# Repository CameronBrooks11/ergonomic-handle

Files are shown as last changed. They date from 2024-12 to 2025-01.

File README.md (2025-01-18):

# Ergonomic Handle

This is an OpenSCAD library to generate an ergonomic handle that distributes hand contact pressure as evenly as possible.

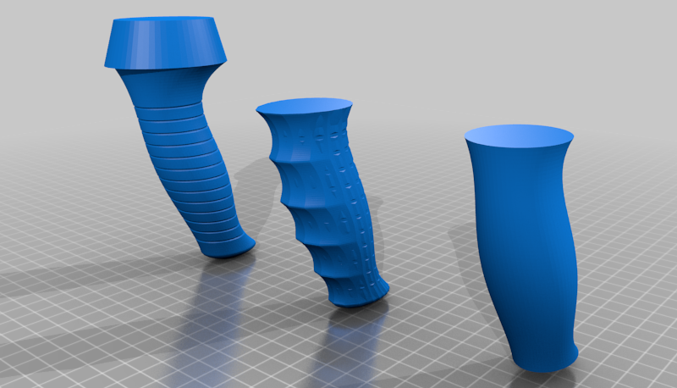
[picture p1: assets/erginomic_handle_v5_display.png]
Ergonomic Handle V5 Render


A further development of "Ergonomic handle based on scientific study": [Thingiverse](https://www.thingiverse.com/thing:5330170) and [Printables](https://www.printables.com/model/154837).

## Summary

The Ergonomic Handle Library is an OpenSCAD library designed to generate ergonomic handles that distribute hand contact pressure as evenly as possible. This library leverages anthropometric data from various populations worldwide to create handles that are both comfortable and scalable to different hand sizes.

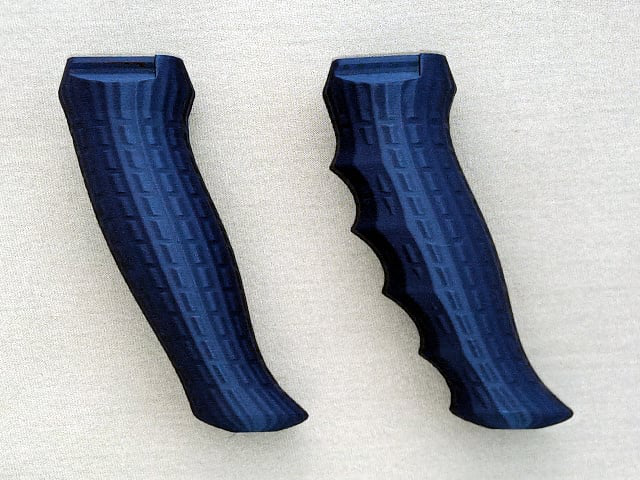
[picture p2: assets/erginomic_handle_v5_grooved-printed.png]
3D Printed Grooved Handle


## Features

- **Scientific Design**: Based on multiple research studies using anthropometric data.
- **Scalable**: Handles can be adjusted to fit any hand size by specifying hand length and width.
- **Customizable**: Various parameters allow for modifications such as finger grooves and handle extensions.
- **Ergonomic**: Designed to distribute pressure evenly across the hand, reducing strain during use.
- **Open Source**: Licensed under Creative Commons - Attribution, allowing for modification and sharing.

## Modules and Parameters

For detailed information on the design see [design details](details.md)!

### `ergonomic_handle`

Renders the body of an ergonomic handle, centered at the origin.

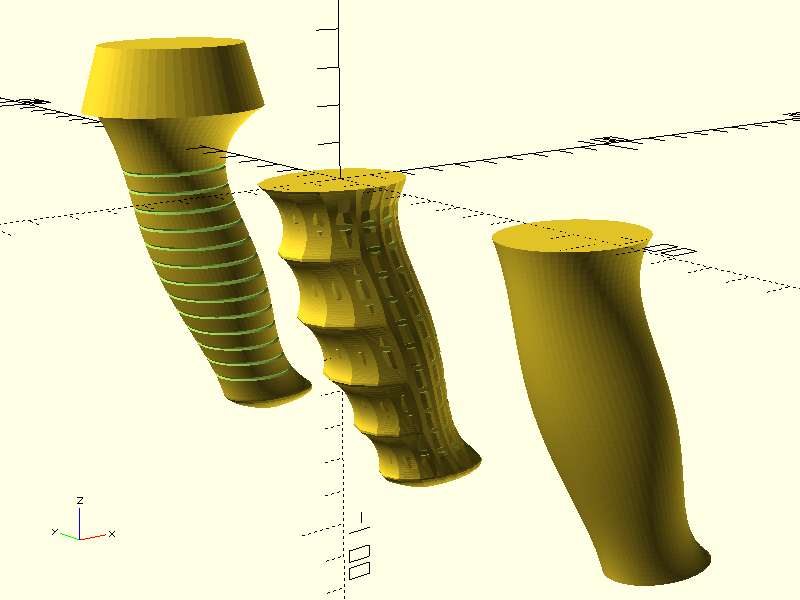
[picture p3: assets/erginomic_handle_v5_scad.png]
OpenSCAD Render


**Parameters:**

- `hand_length` (default: 186): Length of the hand from the tip of the middle finger to the first crease on the wrist, in millimeters.
- `hand_width` (default: 85): Metacarpal breadth; width of the four fingers where they meet the palm, in millimeters.
- `flair` (default: true): Flare out the top and bottom of the front edge for better pull force.
- `bottomcapext` (default: 0): Bottom cap extension. Suggested values: 3 to 8.
- `topext` (default: 0): Top extension, curves extrapolated upward by this amount.
- `groovespc` (default: 0): Groove spacing for improved grip. Suggested spacing: 6-10 mm.
- `fingergroove` (default: false): Enables finger-specific grooves. **Note:** May reduce ergonomic comfort for other hand sizes.
- `tiltangle` (default: 110): Handle tilt angle in degrees. Should be no less than 90.
- `fn` (default: 64): Number of facets in the elliptical cross-section and vertical slices.
- `halfrotate` (default: false): Rotates polygon vertices half of a segment around the ellipse.
- `metacarpal_expansion` (default: 1.12): Expands metacarpal breadth in gripping position. **Range:** 1.10–1.15.
- `groovedepth` (default: 0.6): Depth of grooves, used for creating textured grip.
- `bottomcapscale` (default: 0.3): Scale factor for the bottom-most disc of the handle's base cap.

## Print Settings

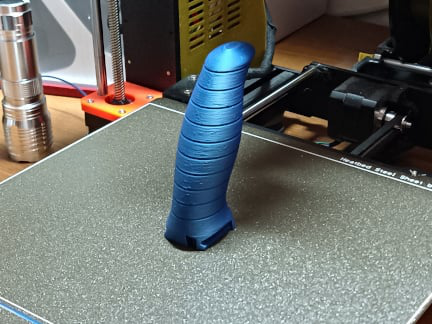
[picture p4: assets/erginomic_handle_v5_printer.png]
Handle on Printer Build Plate


When 3D printing the ergonomic handle, consider the following settings:

- **Printer Brand**: Compatible with Prusa I3 MK3S.
- **Supports**: Not required if printed upside-down. Supports may be needed if printed right-side-up.
- **Infill**: 15% gyroid for optimal strength and material usage.
- **Orientation**: Print the handle upside-down to avoid the need for supports and ensure structural integrity.

**Notes:**

- The handle should be printed upside-down to minimize the need for supports.
- Incorporate a top structure with sliding rails for additional parts to snap into place.

## License

This library is licensed under the Creative Commons - Attribution license (CC BY). You are free to share and adapt the material provided you give appropriate credit.

## Attribution

This project is based on the work of **Alex Matulich**, originally posted on [Thingiverse](https://www.thingiverse.com/thing:5330170) and detailed on his [blog](https://www.nablu.com/2022/03/whose-hands-are-biggest-you-may-be.html). All studies and data used in this library are cited and linked in the original blog article "Whose hands are biggest? You may be surprised."

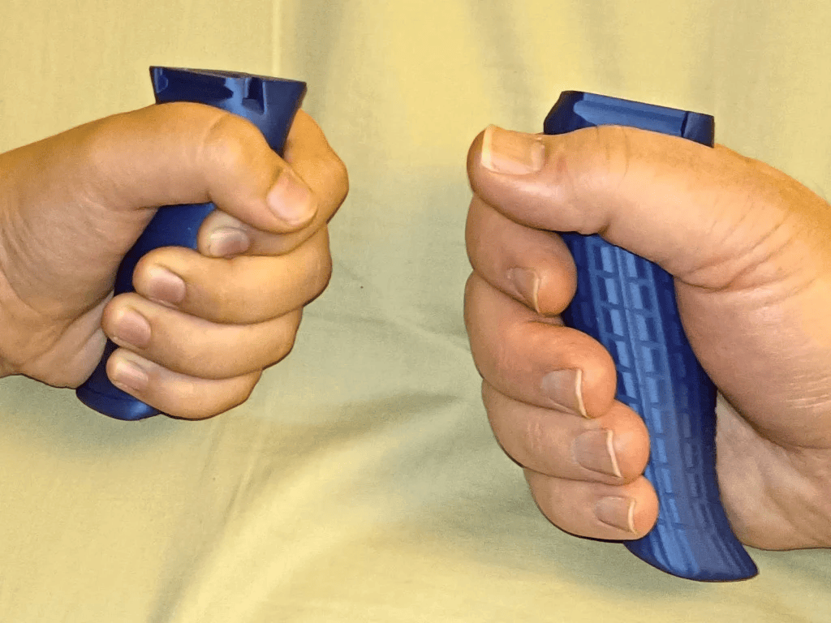
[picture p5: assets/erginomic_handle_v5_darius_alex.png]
Ergonomic Handle Design


For more designs and information, visit Alex's [Thingiverse page](https://www.thingiverse.com/thing:5330170) or his [blog](https://www.nablu.com/2022/03/whose-hands-are-biggest-you-may-be.html).

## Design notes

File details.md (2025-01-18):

# Design Details

An ergonomic handle distributes the hand contact pressure as evenly as possible.

## Basis

The dimensions in this model are based on several research papers using anthropometric data from various populations
around the world. The handle profile is based on a 2020 study in which gripping hands were measured with a contour gauge
to derive the correct curves for an ergonomic handle.

All of these studies are cited and linked in the blog article "[Whose hands are biggest? You may be
surprised.](https://www.nablu.com/2022/03/whose-hands-are-biggest-you-may-be.html)"

The handle contour study was extrapolated by generalizing it to be scalable to any size of hand. Knowing that the handle
height is based on metacarpal breadth (hand width) and the handle cross section sizes are based on hand length, one can
generate vertical and horizontal scale factors for the curve control points given in the study, and thereby obtain a
handle scaled correctly to any size hand.

## Usage

Place this in a searchable location, like the same directory as your script, and near the top, put this line:

use <ergonomic_handle.scad>

## Modules

### Main

`ergonomic_handle(hand_length=185, hand_width=86, flair=true, bottomcapext=0, topext=0, groovespc=0, tiltangle=110, fn=64, halfrotate=false);`

Renders the body of an ergonomic handle. The handle is oriented so that the top surface is centered at the origin.

**Parameters:**

- `hand_length`: Length of hand from tip of middle finger to first crease on wrist. Defaults to `default_hand_length()`.
- `hand_width`: Metacarpal breadth; width of the four fingers where they meet the palm. Defaults to `default_hand_width()`.
- `flair`: Set to `true` to flare out the top and bottom of the front edge for better pull force. When `flair=false`, the handle is generated as described in the referenced study. Defaults to `true`.
- `bottomcapext`: Bottom cap extension. `0` = flat bottom (default). Suggested values range from 3 to 8.
- `topext`: Top extension, curves extrapolated upward by this amount. `0` = no extension (default). The extension extends above the origin.
- `groovespc`: Groove spacing for improved grip. `0` = none (default, or if `fingergroove=true`). Suggested spacing is 6-10 mm. Grooves are 1.2 mm wide and 0.6 mm deep.
- `fingergroove`: Set to `false` for no finger grooves (default), or `true` to include them (this disables `groovespc`). WARNING: Enabling this setting causes the handle to fit ONLY the hand for which it is sized! The grooves are un-ergonomic and uncomfortable if the handle size doesn't match the hand.
- `tiltangle`: Handle tilt angle. `110°` (default) recommended. Should be no less than 90°.
- `fn`: Number of facets (default 64) in elliptical cross-section as well as vertical slices. Vertical slices are always 128 if `fingergroove=true`.
- `halfrotate`: Whether to rotate polygon vertices half of a segment around the ellipse (default `false`). Useful only for overlapping two low-poly handles for interesting textures (see demo).

### Helpers

`ergonomic_handle_top_ellipse(hand_length, hand_width, topext, tiltangle, fn);`

Returns a polygon corresponding to the top surface of the handle (including extension). Parameters are the same as described above. All have defaults if omitted.

`ergonomic_handle_bottom_ellipse(hand_length, hand_width, tiltangle, fn);`

Returns a polygon corresponding to the bottom surface of the handle (excluding bottom cap extension). Useful when not using a bottom cap and you want to match something with the bottom of the handle. Parameters are the same as described above. All have defaults if omitted.

Additionally, `ergonomic_handle_height(hand_width, metacarpal_expansion)` may be used to get the height of the basic handle body without extensions. This is the same as `hand_width * metacarpal_expansion`.

The handle is rendered with the top center at origin. The bottom of the handle (excluding extension cap) is `ergonomic_handle_height()` below the origin.

### Default Parameters

All default parameters are overridden in module arguments.

These hand dimensions (186 mm length, 85 mm breadth) were calculated from data found in various journal articles, broken down by nationality: Bangladeshi, Czech, Filipino, German, central Indian, East Indian, Iranian, Korean, Jordanian, Mexican, Taiwanese, Turkish, and Vietnamese. The average male hand length is 186 mm (range 173-198) and breadth is 85 mm (range 78-98). The average female hand length is 170 mm (range 161-180) and breadth is 76 mm (range 68-92). Using the average male size should also cover nearly all adult females and all children.

When plotted by hand area (length x width), the populations sort themselves into three obvious groups with similar hand sizes. Vietnamese and Indian females have the smallest hands, followed closely by Turkish and Bangladeshi females. Filipino males seem to be an outlier with the largest hands. Other than Filipino males, the group with the largest hands includes Czech, Iranian, Jordanian, Turkish, and German males, as well as Filipino females.

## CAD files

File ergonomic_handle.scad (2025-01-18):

/*
 * Ergonomic handle
 * by Alex Matulich
 * Verson 5.1, May 2022
 *
 * Revised and uploaded to GitHub for continued development as well as reference and visibility on December 5th, 2024.
 *
 */

hand_length = 186;           // Default hand length for scaling (mm)
hand_width = 85;             // Default metacarpal breadth (mm)
metacarpal_expansion = 1.12; // Typical metacarpal breadth expansion in grip position (10%-15%)
flair = true;                // Enable top/bottom flaring for enhanced pull force
fingergroove = true;         // Add grooves for finger-specific ergonomic fit
groovespc = 8;               // Spacing between grooves (mm)
groovedepth = 0.6;           // Depth of grooves for grip (mm)
tiltangle = 110;             // Tilt angle of the handle (degrees)
topext = 0;                  // No top extension added
bottomcapext = 6;            // Bottom cap extended by 6 mm
bottomcapscale = 0.3;        // Bottom cap scaled to 30% of the handle cross-section
fn = 64;                     // Number of facets for ellipses
halfrotate = false;          // No half-rotation of polygon vertices

// Generate the ergonomic handle with the defined parameters
ergonomic_handle(hand_length = hand_length, hand_width = hand_width, metacarpal_expansion = metacarpal_expansion,
                 flair = flair, fingergroove = fingergroove, groovespc = groovespc, groovedepth = groovedepth,
                 tiltangle = tiltangle, topext = topext, bottomcapext = bottomcapext, bottomcapscale = bottomcapscale,
                 fn = fn, halfrotate = halfrotate);

// Dummy module to stop customizer from picking up internal variables
module dummy()
{
}

// -------------------------------
// ---------- constants ----------
// -------------------------------

// Handle curve coefficients
ehandle_coeff_default = [   // coefficents for default handle based on all test subjects

    // curve E (forward profile)
    [ 0.10820685778527288,
     7.8071566553000377e-002,
    -0.11713845806508627 ],
    // curve F (side profile)
    [ 8.9094997189434533e-002,
    -0.23994552971632244,
     1.0934064033888202,
    -1.5902142712055265,
     0.70892877695967604 ],
    // curve G (rear profile)
    [ 0.10820685778528655,
    -0.46856937731734472,
     1.9272376487779372,
    -2.9629722410641546,
     1.4995260044545953 ]
];

ehandle_coeff_fwdflair = [  // coefficients for handle with forward profile flared at the ends

    // curve E - assumes 12% metacarpal expansion
    [0.11246945332942532,
    -1.8795070341676573e-002,
     0.36187545606899507,
    -0.83803954628607691,
     0.46058029602811634],
     // curve F
     ehandle_coeff_default[1],
     // curve G
     ehandle_coeff_default[2]
];

// trochoid finger groove parameters
// finger width porportions from anthropometric data
thumbfrac = 0.231959853553746;      // thumb fraction of hand width
forefingerfrac = 0.200542328752527; // forefinger fraction of hand width

/* 0.261856394119384, 0.262553059392204, 0.251706774167261, 0.22388377232115,0.22388377232115
four fingers only - doesn't work well */
fingwidfrac = [
    // thumb plus four fingers
    0.5 * (thumbfrac + forefingerfrac),
    0.5 * (thumbfrac + forefingerfrac), // split total width of thumb+forefinger
    0.201238475943949,                  // middle finger
    0.193454805146993,                  // ring finger
    0.172804536602786,                  // pinky
    0.172804536602786                   // copy pinky to avoid array index overrun in trochoid()
];

trochoid_amp = 0.65; // trochoid amplitude, must be between 0.5 and 0.9

// -----------------------------
// ---------- modules ----------
// -----------------------------

// render the handle
module ergonomic_handle(hand_length = default_hand_length(), hand_width = default_hand_width(), flair = true,
                        bottomcapext = 0, topext = 0, groovespc = 0, fingergroove = false, tiltangle = 110, fn = 64,
                        halfrotate = false, metacarpal_expansion = 1.12, groovedepth = 0.6, bottomcapscale = 0.3)
{
    if (metacarpal_expansion < 1.10 || metacarpal_expansion > 1.15)
    {
        echo("WARNING: metacarpal_expansion must be between 1.10 and 1.15. Adjusting to fit the valid range.");
        metacarpal_expansion = max(1.10, min(metacarpal_expansion, 1.15));
    }
    ehdcoeff = flair ? ehandle_coeff_fwdflair : ehandle_coeff_default;
    ecof = hand_length * ehdcoeff[0];                                  // scaled front profile coefficients
    fcof = hand_length * ehdcoeff[1];                                  // scaled side profile coefficients
    gcof = hand_length * ehdcoeff[2];                                  // scaled rear profile coefficients
    ehlen = ergonomic_handle_height(hand_width, metacarpal_expansion); // length of handle
    bcapext = bottomcapext / ehlen;                                    // unit-scaled end cap extension
    t_ext = topext / ehlen;                                            // unit-scaled top extension
    tfwx = fingergroove ? trochoid(0, ehlen) : 0;
    bfwx = fingergroove ? trochoid(ehlen, ehlen) : 0;
    vfn = fingergroove ? 128 : fn;

    estack = [ // stack of ellipse cross sections
       // top extension, if any
        if (topext > 0)
            for(z=[-t_ext:1/fn:-0.01/ehlen])
                let(xmin = polynomial(gcof, z),
                    xmax = polynomial(ecof, z),
                    ymax = polynomial(fcof, z))
                    elev_ellipse(xmin, xmax, ymax, z*ehlen, tiltangle, fn, tfwx, halfrotate),

        // main body of handle
        for(i=[0:vfn])
            let(z=i/vfn,
                fwx = fingergroove ? trochoid(z*ehlen, ehlen) : 0,
                xmin = polynomial(gcof, z),
                xmax = polynomial(ecof, z),
                ymax = polynomial(fcof, z))
                    elev_ellipse(xmin, xmax, ymax, z*ehlen, tiltangle, fn, fwx, halfrotate),

        // bottom cap, if any
        if (bottomcapext > 0)
            for(z=[1+0.5/ehlen:1/ehlen:1+bcapext-0.01/ehlen])
                let(scl = bottomcapscale+(1-bottomcapscale)*cos(90*(z-1)/bcapext), xmin = scl*polynomial(gcof, z), xmax = scl*polynomial(ecof, z), ymax = scl*polynomial(fcof, z))
                    elev_ellipse(xmin, xmax, ymax, z*ehlen, tiltangle, fn, bfwx, halfrotate),
        // last ellipse of bottom cap
        if (bottomcapext > 0)
            let(z=1+bcapext, scl=bottomcapscale, xmin = scl*polynomial(gcof, z), xmax = scl*polynomial(ecof, z), ymax = scl*polynomial(fcof, z))
                elev_ellipse(xmin, xmax, ymax, z*ehlen, tiltangle, fn, bfwx, halfrotate)
    ];
    // render the object right-side-up
    rotate([ 0, 180, 0 ]) difference()
    {
        polyhedron_stack(estack);
        if (groovespc > 0 && !fingergroove)
            for (h = [1.5 * groovespc:groovespc:ehlen - groovespc])
                groove_ellipse(h);
    }

    module groovecutter(groovedepth)
    {
        polygon(points = [ [ -groovedepth, 0 ], [ 4 - groovedepth, 4 ], [ 4 - groovedepth, -4 ] ]);
    }

    module groove_ellipse(ht)
    {
        let(z = ht / ehlen, xmin = polynomial(gcof, z), xmax = polynomial(ecof, z), ymax = polynomial(fcof, z),
            semimajoraxis = 0.5 * (xmax + xmin))
            multmatrix(m =
                           [
                               [ 1, 0, cos(tiltangle), semimajoraxis - xmin + ht * cos(tiltangle) ],
                               [ 0, ymax / semimajoraxis, 0, 0 ], [ 0, 0, 1, ht ], [ 0, 0, 0, 1 ]
                           ]) rotate([ 0, 0, 180 ]) rotate_extrude(angle = 360, $fn = fn, convexity = 4)
                translate([ semimajoraxis, 0, 0 ]) groovecutter(groovedepth);
    }
}

// Build a polyhedron object from a stack of polygons. It is assumed that each polygon has [x,y,z] coordinates as its
// vertices, and the ordering of vertices follows the right-hand-rule with respect to the direction of propagation of
// each successive polygon.
module polyhedron_stack(stack)
{
    nz = len(stack);    // number of z layers
    np = len(stack[0]); // number of polygon vertices
    facets = [
        [for (j = [0:np - 1]) j], // close first opening
        for (i = [0:nz - 2]) for (j = [0:np - 1])
            let(k1 = i * np + j, k4 = i * np + ((j + 1) % np), k2 = k1 + np, k3 = k4 + np)[k1, k2, k3, k4],
        [for (j = [np * nz - 1:-1:np * nz - np]) j], // close last opening
    ];
    polyhedron(flatten(stack), facets, convexity = 6);
}
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

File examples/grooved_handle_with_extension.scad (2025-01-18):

use <../ergonomic_handle.scad>

// Grooved handle with top extension, bottom cap, and matching structure on top surface

ergonomic_handle(hand_length = 178, hand_width = 79.4, bottomcapext = 6, topext = 10, groovespc = 6);
translate([ 0, 0, 10 ]) linear_extrude(20, scale = 0.8)
    ergonomic_handle_top_ellipse(hand_length = 177.9, hand_width = 79.4, topext = 10);

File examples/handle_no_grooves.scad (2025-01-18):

use <../ergonomic_handle.scad>

// Default handle with no finger grooves
ergonomic_handle(hand_length = 178, hand_width = 79.4, fingergroove = false);

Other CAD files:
examples/low_facet_handle_with_grooves.scad

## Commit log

2024-12-05 organized and added customizer profiles
    [demo.scad, ergonomic-handle.csv, ergonomic_handle.scad]
2025-01-18 did some revision of repo
    [demo.scad, ergonomic_handle.scad, grooved_handle_with_extension.scad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]
2026-11-13 fix: expansion clamp, helper defaults and licence text
    metacarpal_expansion outside 1.10-1.15 printed 'Adjusting to fit the
    valid range' but was used as given, because the clamped value was
    assigned inside an if block. With 1.30 and an 85 mm hand width the
    handle was 110.5 mm tall; it is now 97.75 mm, 85 x 1.15. The clamp
    lives in ergonomic_handle_height(), which the two ellipse modules also
    use.
    ergonomic_handle_top_ellipse() and ergonomic_handle_bottom_ellipse()
    defaulted to fingergroove = true while ergonomic_handle() defaults to
    false, so a cap built on the helper overhung a default handle: 55.34 mm
    against 55.14 mm in the extension example. Both now default to false.
    That example also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
